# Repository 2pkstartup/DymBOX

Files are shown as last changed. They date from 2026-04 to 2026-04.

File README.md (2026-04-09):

# DymBOX

Regulátor teploty pro udírnu postavený na mikrokontroléru **ATmega8**.

Měří teplotu pomocí DS18B20, zobrazuje ji na 3-místném 7-segmentovém displeji a řídí ventilátor (PWM) a topnou spirálu (ON/OFF s hysterezí). Žádaná teplota a otáčky ventilátoru se nastavují rotačním enkodérem.

## Vlastnosti

- **Měření teploty** – DS18B20 (1-Wire), rozlišení 0.1 °C
- **3-místný 7-segment display** – multiplexovaný v Timer0 ISR (~163 Hz/číslice)
- **Rotační enkodér KY-040** – nastavení žádané teploty a otáček ventilátoru
- **PWM ventilátor** – 11 kroků (0–100 % po 10 %), Timer1 Fast PWM 8-bit na ~977 Hz
- **Topná spirála** – ON/OFF regulace s hysterezí 5 °C
- **Nastavitelný setpoint** – výchozí 32.0 °C, editace po 0.1 °C

## Struktura repozitáře

```
DymBOX/
├── fw/                 # Firmware (C, ATmega8)
│   ├── main.c
│   ├── CMakeLists.txt
│   ├── Makefile
│   ├── cmake/          # AVR-GCC toolchain soubor
│   └── README.md
├── hw/                 # Hardware (KiCad 8)
│   ├── DymBOX_AVR.kicad_sch    # Schéma
│   ├── DymBOX_AVR.kicad_pcb    # PCB layout
│   ├── gerber/                  # Gerber soubory pro výrobu
│   ├── dymbox_gerber.zip        # Zabalené gerbery
│   ├── 2pkstartup.pretty/      # Vlastní footprinty
│   └── DymBOX_AVR-backups/
└── README.md
```

## Hardware

Schéma a PCB jsou navrženy v **KiCadu**. Gerber soubory připravené k výrobě najdete v `hw/gerber/` nebo jako `hw/dymbox_gerber.zip`.

### Hlavní komponenty

| Součástka | Popis |
|---|---|
| ATmega8 | Hlavní MCU (16 MHz) |
| DS18B20 | Digitální teploměr (1-Wire) |
| 3× 7-segment (common anode) | Displej – multiplexovaný |
| KY-040 | Rotační enkodér s tlačítkem |
| Ventilátor | PWM řízený (~977 Hz) |
| Topná spirála | ON/OFF přes PB2 |

### Zapojení pinů

```
PORTB: PB0 = seg A       PB1 = PWM fan    PB2 = heater
PORTC: PC0 = seg E       PC1 = seg D      PC2 = seg DP
       PC3 = seg C       PC4 = seg G      PC5 = DS18B20
PORTD: PD0 = ENC SW      PD1 = DIG3       PD2 = DIG2
       PD3 = ENC CLK     PD4 = ENC DT     PD5 = DIG1
       PD6 = seg B       PD7 = seg F
```

## Firmware

Firmware je napsaný v **C** pro AVR a překládá se pomocí `avr-gcc` + CMake.

### Požadavky

```bash
sudo apt install gcc-avr avr-libc binutils-avr avrdude cmake
```

### Kompilace a nahrání

```bash
cd fw
cmake -B build -DCMAKE_TOOLCHAIN_FILE=cmake/avr-gcc.cmake
cmake --build build              # Kompilace
cmake --build build --target flash   # Nahrání do MCU (USBasp)
cmake --build build --target fuses   # Nastavení fuses
```

### Velikost firmware

```
Program:  ~2186 bytes (26.7 % Flash)
Data:       ~61 bytes  (6.0 % SRAM)
```

## Ovládání

Zařízení má 3 režimy zobrazení:

| Režim | Displej | Ovládání |
|---|---|---|
| **Teplota** (výchozí) | `XX.X` – aktuální teplota | Otočení → ventilátor · Stisk → editace setpointu |
| **Ventilátor** | `FXX` – rychlost v % | Otočení → změna po 10 % · Po 2 s → zpět na teplotu |
| **Editace setpointu** | `XX.X` + DP1 svítí | Otočení → změna po 0.1 °C · Stisk → uložit a zpět |

Topná spirála se indikuje rozsvícením DP3 (poslední tečka).

## Regulace teploty

ON/OFF regulace s hysterezí:

| Podmínka | Akce |
|---|---|
| teplota ≤ setpoint − 5 °C | Spirála **ON** |
| teplota ≥ setpoint | Spirála **OFF** |
| v pásmu hystereze | Beze změny |

## Licence

Tento projekt je volně k použití.

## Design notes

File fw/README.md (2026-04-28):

# dymbox – Regulátor teploty s ATmega8

Regulátor teploty postavený na mikrokontroléru **ATmega8** s 3-místným 7-segmentovým displejem, rotačním enkodérem, teploměrem DS18B20, PWM výstupem pro ventilátor a ON/OFF řízením topné spirály.

## Vlastnosti

- **Měření teploty** – DS18B20 (1-Wire), rozlišení 0.1 °C
- **3-místný 7-segment display** – multiplexovaný v Timer0 ISR (~163 Hz/číslice)
- **Rotační enkodér KY-040** – nastavení žádané teploty a otáček ventilátoru
- **PWM ventilátor** – 21 kroků (0–100 % po 5 %), Timer1 Fast PWM 8-bit na ~488 Hz
- **Topná spirála** – ON/OFF regulace s hysterezí 5 °C, signalizace DP3
- **Nastavitelný setpoint** – výchozí 32.0 °C, editace po 0.1 °C

## Zapojení pinů

### 7-segment display (common anode, active LOW)

| Segment | Pin ATmega8 | Port |
|---|---|---|
| A | PB0 | PORTB |
| B | PD5 | PORTD |
| C | PC3 | PORTC |
| D | PC1 | PORTC |
| E | PC0 | PORTC |
| F | PD7 | PORTD |
| G | PC4 | PORTC |
| DP | PC2 | PORTC |

### Výběr číslic (active LOW)

| Číslice | Pin | Pozice |
|---|-----|---|
| DIG1 | PD6 | Stovky |
| DIG2 | PD2 | Desítky |
| DIG3 | PD1 | Jednotky |

### Rotační enkodér KY-040

| Signál | Pin |
|---|-----|
| CLK (A) | PD3 |
| DT (B)  | PD4 |
| SW | PD0 |
| + | VCC |
| GND | GND |

### DS18B20 teploměr

| Pin DS18B20 | Kam |
|---|-----|
| DQ (data) | PC5 + 4.7 kΩ pull-up na VCC |
| VCC | VCC (3.3–5 V) |
| GND | GND |

### Výstupy

| Funkce | Pin | Typ |
|---|-----|-----|
| Ventilátor (PWM) | PB1 (OC1A) | Fast PWM ~488 Hz |
| Topná spirála | PB2 | SW ON/OFF (active HIGH) |

### Souhrn obsazení pinů

```
PORTB: PB0 = seg A       PB1 = PWM fan    PB2 = heater    PB3–PB5 = volné
PORTC: PC0 = seg E       PC1 = seg D      PC2 = seg DP    PC3 = seg C
       PC4 = seg G       PC5 = DS18B20
PORTD: PD0 = ENC SW      PD1 = DIG3       PD2 = DIG2
       PD3 = ENC CLK     PD4 = ENC DT     PD5 = seg B
       PD6 = DIG1        PD7 = seg F
```

## Ovládání

Aplikace má 3 režimy zobrazení:

### 1. Teplota (výchozí)

Zobrazuje aktuální teplotu ve formátu **XX.X** (tečka za druhým digitem).

- **Otočení enkodéru** → přepne na zobrazení ventilátoru
- **Stisk tlačítka** → přepne do editace setpointu
- **DP3 (poslední tečka)** svítí, pokud topí spirála

### 2. Ventilátor (FXX)

Zobrazuje rychlost ventilátoru ve formátu **FXX** (např. F50 = 50 %). Při 100 % zobrazí **100**.

- **Otočení enkodéru** → mění rychlost po 5 % (0–100 %)
- **Stisk tlačítka** → přepne do editace setpointu
- Po **2 sekundách** bez pohybu se automaticky vrátí na zobrazení teploty

### 3. Editace setpointu

Zobrazuje žádanou teplotu ve formátu **XX.X** s rozsvícenou **DP1** (první tečka) jako indikací editačního režimu.

- **Otočení enkodéru** → mění hodnotu po 0.1 °C (rozsah 0.0–99.9 °C)
- **Stisk tlačítka** → uloží hodnotu a vrátí se na zobrazení teploty

## Regulace teploty

Topná spirála je řízena jednoduchou ON/OFF regulací s hysterezí:

| Podmínka | Akce |
|---|---|
| teplota ≤ setpoint − 5 °C | Spirála **ON** (DP3 svítí) |
| teplota ≥ setpoint | Spirála **OFF** (DP3 nesvítí) |
| v pásmu hystereze | Bez změny |

Výchozí setpoint: **32.0 °C**, hystereze: **5.0 °C** (konstanta `HEATER_HYST`).

## Požadavky

- `avr-gcc`, `avr-libc`, `binutils-avr`
- `avrdude`
- `cmake` (≥ 3.20)
- Programátor USBasp (nebo jiný – viz `PROGRAMMER` v CMakeLists.txt)

### Instalace toolchainu (Debian/Ubuntu)

```bash
sudo apt install gcc-avr avr-libc binutils-avr avrdude
```

## Kompilace a nahrání

```bash
cmake -B build -DCMAKE_TOOLCHAIN_FILE=cmake/avr-gcc.cmake   # Konfigurace
cmake --build build                                          # Kompilace
cmake --build build --target flash                           # Nahrání do MCU
cmake --build build --target fuses                           # Nastavení fuses
```

### Hodnoty fuses (externí krystal 8 MHz)

| Fuse | Hodnota | Popis |
|---|---|---|
| lfuse | `0xFF` | CKSEL=1111 (externí krystal), SUT=11 (65 ms startup) |
| hfuse | `0xD9` | CKOPT=1 (low-power mode), SPIEN povolen |

> **Pozor:** Po nastavení `lfuse=0xFF` ATmega očekává externí krystal. Bez něj chip nenastartuje.

### Velikost firmware

```
Program:  ~2172 bytes (26.5% Full)
Data:       ~71 bytes  (6.9% Full)
```

## Konfigurace

Hlavní konstanty v `main.c`:

| Konstanta | Hodnota | Popis |
|---|---|---|
| `F_CPU` | 8 MHz | Frekvence externího krystalu (CMakeLists.txt) |
| `HEATER_HYST` | 50 (5.0 °C) | Hystereze topné spirály (v 1/10 °C) |
| `HEATER_PERIOD` | 4880 | Perioda ON/OFF cyklu (~10 s) |
| Výchozí setpoint | 320 (32.0 °C) | Žádaná teplota (v 1/10 °C) |
| Výchozí fan | 10 (50 %) | Výchozí rychlost ventilátoru (krok 0–20) |

## Schéma zapojení

```
                    ATmega8
                 ┌───────────┐
    seg A ← PB0 ┤1        28├ PC5 → DS18B20 DQ
  PWM fan ← PB1 ┄2        27┤ PC4 → seg G
   heater ← PB2 ┄3        26┤ PC3 → seg C
           PB3 ┄4        25┤ PC2 → seg DP
           PB4 ┄5        24┤ PC1 → seg D
           PB5 ┄6        23┤ PC0 → seg E
               ┤7        22├ GND
               ┤8        21├ AREF
               ┤9        20├ VCC
               ┤10       19├ PB5 (SCK)
  ENC SW → PD0 ┤11       18├ PB4 (MISO)
    DIG3 ← PD1 ┤12       17├ PB3 (MOSI)
    DIG2 ← PD2 ┤13       16├ PB2
 ENC CLK → PD3 ┤14       15├ PB1
  ENC DT → PD4 ┤15       14├ PD7 → seg F
   seg B ← PD5 ┤16       13├ PD6 → DIG1
                 └───────────┘
```

## Licence

Tento projekt je volně k použití.

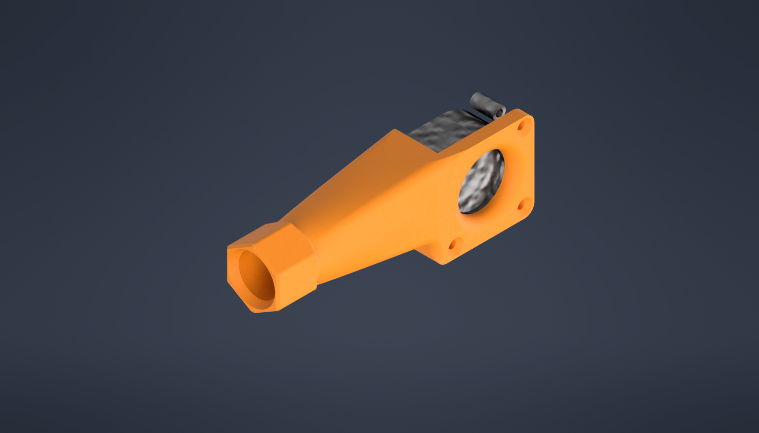
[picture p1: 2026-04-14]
3d/DymBOX-vent02.png

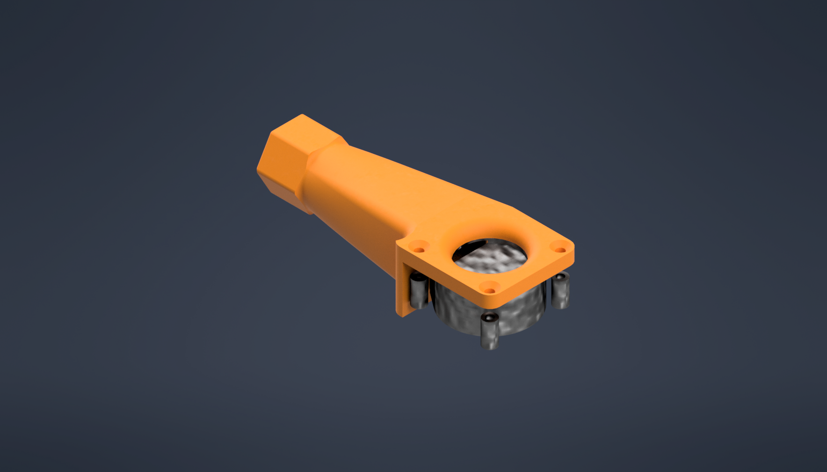
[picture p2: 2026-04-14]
3d/DymBOX-vent01.png

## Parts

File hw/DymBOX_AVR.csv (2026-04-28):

Id | Designator | Footprint | Quantity | Designation | Supplier and ref
1 | C1 | CP_Radial_D16.0mm_P7.50mm | 1 | 3m3F
2 | C2 | C_1206_3216Metric_Pad1.33x1.80mm_HandSolder | 1 | 10uF
3 | C4, C5 | C_0805_2012Metric_Pad1.18x1.45mm_HandSolder | 2 | 22pF
4 | C6 | C_0805_2012Metric_Pad1.18x1.45mm_HandSolder | 1 | C_Small
5 | C8 | C_0805_2012Metric_Pad1.18x1.45mm_HandSolder | 1 | 100nF
6 | C9, C10 | C_0805_2012Metric_Pad1.18x1.45mm_HandSolder | 2 | 22uF
7 | D1, D2 | D_DO-35_SOD27_P7.62mm_Horizontal | 2 | 1N4148
8 | D3 | Diode_Bridge_DIP-4_W5.08mm_P2.54mm | 1 | DB155-YAN
9 | F1 | Fuseholder_Clip-5x20mm_Littelfuse_111_Inline_P20.00x5.00mm_D1.05mm_Horizontal | 1 | 500mA
10 | F2 | Fuseholder_Clip-5x20mm_Littelfuse_111_Inline_P20.00x5.00mm_D1.05mm_Horizontal | 1 | 16A
11 | J1 | faston_6.3 | 1 | L 230V
12 | J2, J3 | faston_6.3 | 2 | N 230V
13 | J4 | faston_6.3 | 1 | Conn_01x01_Pin
14 | J5 | TerminalBlock_Phoenix_PT-1,5-3-3.5-H_1x03_P3.50mm_Horizontal | 1 | TAD05-03-1-L-G
15 | J6 | TerminalBlock_Phoenix_PT-1,5-2-3.5-H_1x02_P3.50mm_Horizontal | 1 | TAD05-02-1-L-G
16 | J7 | PinHeader_2x05_P2.54mm_Vertical | 1 | ZL202-10G
17 | K1 | Relay_SPDT_Schrack-RT1-16A-FormC_RM5mm | 1 | RT314A24
18 | L1 | L_1210_3225Metric_Pad1.42x2.65mm_HandSolder | 1 | 4u7H
19 | Q1, Q2, Q5 | TO-92_HandSolder | 3 | BC327
20 | Q3, Q4 | TO-92_HandSolder | 2 | BS170
21 | R1, R16, R17 | R_Axial_DIN0204_L3.6mm_D1.6mm_P5.08mm_Horizontal | 3 | 10k
22 | R2, R3, R4, R5, R6, R7, R8, R9, R14, R15 | R_Axial_DIN0204_L3.6mm_D1.6mm_P5.08mm_Horizontal | 10 | 330
23 | R10, R11, R12 | R_Axial_DIN0204_L3.6mm_D1.6mm_P5.08mm_Horizontal | 3 | 1k
24 | R13 | R_Axial_DIN0204_L3.6mm_D1.6mm_P5.08mm_Horizontal | 1 | 4k7
25 | SW2 | RotaryEncoder_Alps_EC12E-Switch_Vertical_H20mm_CircularMountingHoles | 1 | RotaryEncoder_Switch
26 | TR1 | Transformer_Breve_TEZ-38x45 | 1 | TEZ6.0-D-1
27 | U1 | DIP-28_W7.62mm | 1 | ATmega8A-P
28 | U2 | FYT-5631BUHR-21 | 1 | FYT-5631BUHR-21
29 | U4 | TSOT-23-6 | 1 | AP63205WU
30 | Y1 | Crystal_HC49-U_Vertical | 1 | 49-8.000MEEJ-B

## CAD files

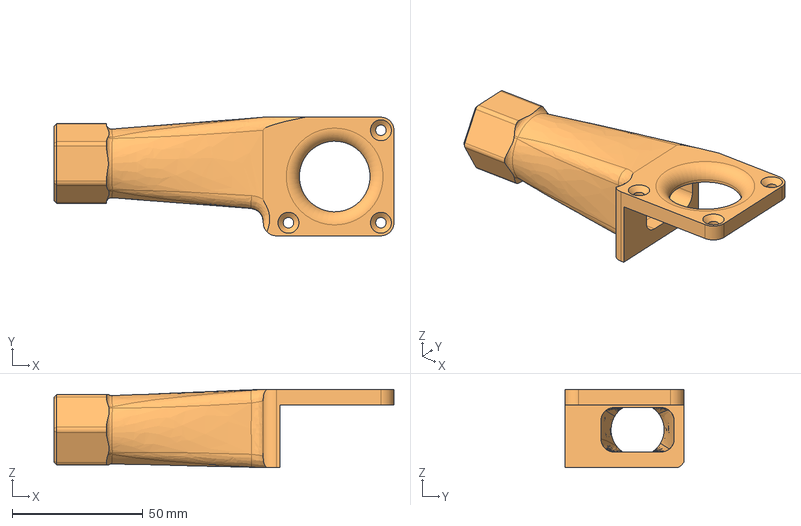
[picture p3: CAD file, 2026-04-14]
3d/DymBOX-ventilator.stp
130.0 x 45.4 x 30.0 mm

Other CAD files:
3d/DymBOX-ventilator.stl

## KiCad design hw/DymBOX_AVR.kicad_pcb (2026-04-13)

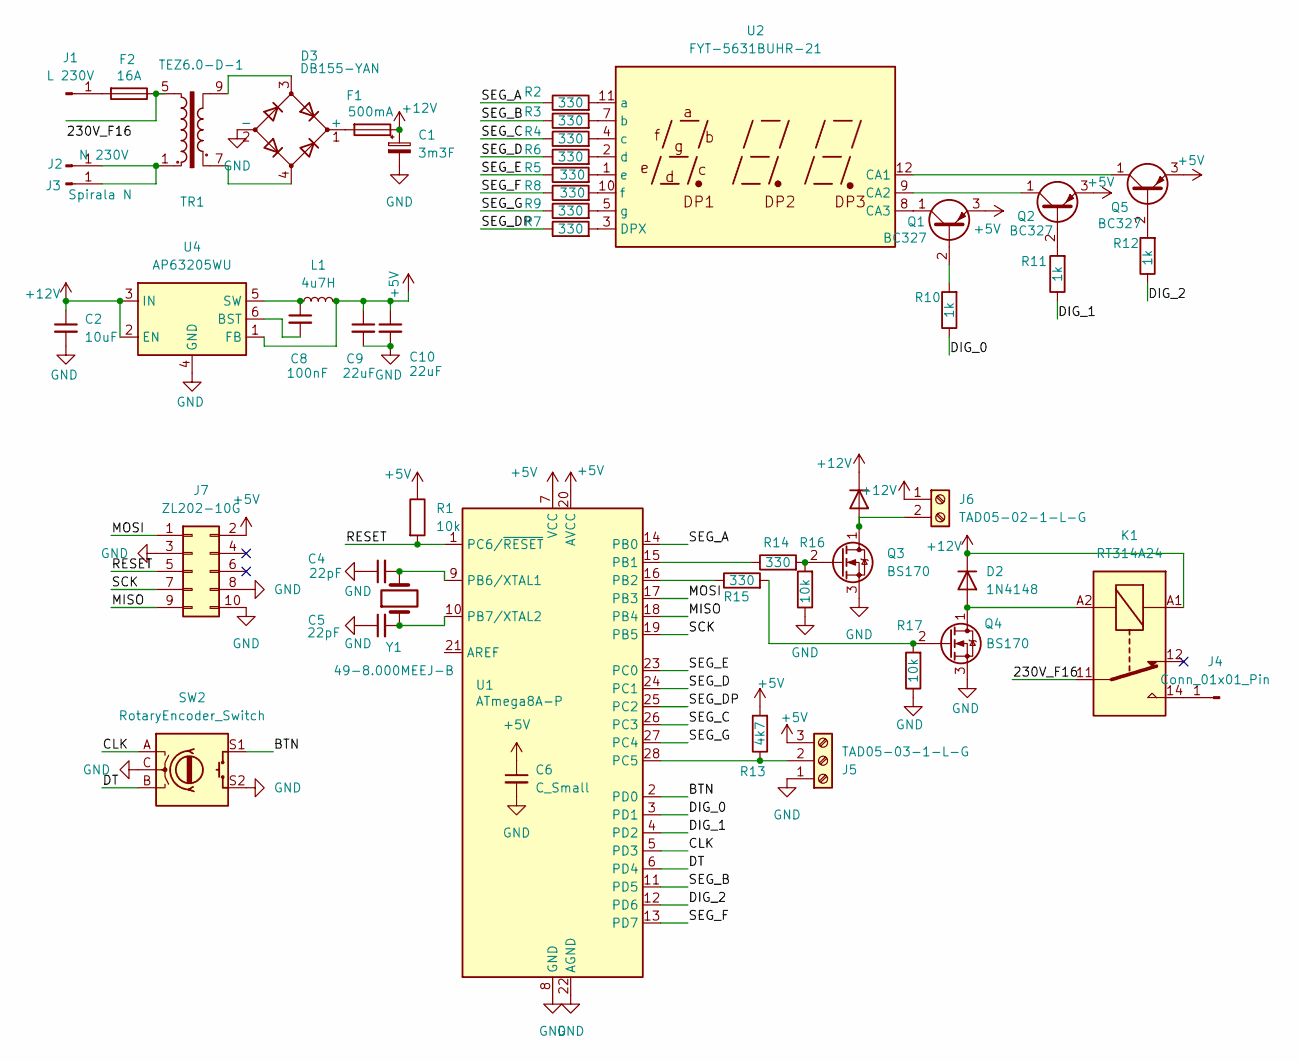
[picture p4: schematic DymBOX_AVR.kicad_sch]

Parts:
C1: 3m3F; CP_Radial_D16.0mm_P7.50mm
C2: 10uF; C_1206_3216Metric_Pad1.33x1.80mm_HandSolder
C4, C5: 22pF; C_0805_2012Metric_Pad1.18x1.45mm_HandSolder
C6: C_Small; C_0805_2012Metric_Pad1.18x1.45mm_HandSolder
C8: 100nF; C_0805_2012Metric_Pad1.18x1.45mm_HandSolder
C9, C10: 22uF; C_0805_2012Metric_Pad1.18x1.45mm_HandSolder
D1, D2: 1N4148; D_DO-35_SOD27_P7.62mm_Horizontal
D3: DB155-YAN; Diode_Bridge_DIP-4_W5.08mm_P2.54mm
F1: 500mA; Fuseholder_Clip-5x20mm_Littelfuse_111_Inline_P20.00x5.00mm_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
F2: 16A; Fuseholder_Clip-5x20mm_Littelfuse_111_Inline_P20.00x5.00mm_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
J1: L 230V; faston_6.3
J2: N 230V; faston_6.3
J3: Spirala N; faston_6.3
J4: Conn_01x01_Pin; faston_6.3
J5: TAD05-03-1-L-G; TerminalBlock_Phoenix_PT-1,5-3-3.5-H_1x03_P3.50mm_Horizontal
J6: TAD05-02-1-L-G; TerminalBlock_Phoenix_PT-1,5-2-3.5-H_1x02_P3.50mm_Horizontal
J7: ZL202-10G; PinHeader_2x05_P2.54mm_Vertical
K1: RT314A24; Relay_SPDT_Schrack-RT1-16A-FormC_RM5mm
L1: 4u7H; L_1210_3225Metric_Pad1.42x2.65mm_HandSolder
Q1, Q2, Q5: BC327; TO-92_HandSolder
Q3, Q4: BS170; TO-92_HandSolder
R1, R16, R17: 10k; R_Axial_DIN0204_L3.6mm_D1.6mm_P5.08mm_Horizontal
R2, R3, R4, R5, R6, R7, R8, R9, R14, R15: 330; R_Axial_DIN0204_L3.6mm_D1.6mm_P5.08mm_Horizontal
R10, R11, R12: 1k; R_Axial_DIN0204_L3.6mm_D1.6mm_P5.08mm_Horizontal
R13: 4k7; R_Axial_DIN0204_L3.6mm_D1.6mm_P5.08mm_Horizontal
SW2: RotaryEncoder_Switch; RotaryEncoder_Alps_EC12E-Switch_Vertical_H20mm_CircularMoun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
TR1: TEZ6.0-D-1; Transformer_Breve_TEZ-38x45
U1: ATmega8A-P; DIP-28_W7.62mm
U2: FYT-5631BUHR-21
U4: AP63205WU; TSOT-23-6
Y1: 49-8.000MEEJ-B; Crystal_HC49-U_Vertical

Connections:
+5V: C6.1, C9.1, C10.1, J5.3, J7.2, L1.2, Q1.3 (E), Q2.3 (E), Q5.3 (E), R1.1, R13.2, U1.7 (VCC), U1.20 (AVCC), U4.1 (FB)
+12V: C1.1, C2.1, D1.1 (K), D2.1 (K), F1.1, J6.1, K1.A1, U4.2 (EN), U4.3 (IN)
/BTN: SW2.S1, U1.2 (PD0)
/CLK: SW2.A, U1.5 (PD3)
/DIG_0: R10.1, U1.3 (PD1)
/DIG_1: R11.1, U1.4 (PD2)
/DIG_2: R12.1, U1.12 (PD6)
/DT: SW2.B, U1.6 (PD4)
/MISO: J7.9, U1.18 (PB4)
/MOSI: J7.1, U1.17 (PB3)
/RESET: J7.5, R1.2, U1.1 (PC6/~RESET)
/SCK: J7.7, U1.19 (PB5)
/SEG_A: R2.1, U1.14 (PB0)
/SEG_B: R3.1, U1.11 (PD5)
/SEG_C: R4.1, U1.26 (PC3)
/SEG_D: R6.1, U1.24 (PC1)
/SEG_DP: R7.1, U1.25 (PC2)
/SEG_E: R5.1, U1.23 (PC0)
/SEG_F: R8.1, U1.13 (PD7)
/SEG_G: R9.1, U1.27 (PC4)
GND: C1.2, C2.2, C4.1, C5.1, C6.2, C9.2, C10.2, D3.2 (-), J5.1, J7.3, J7.8, J7.10, Q3.3 (S), Q4.3 (S), R16.1, R17.1, SW2.C, SW2.S2, U1.8 (GND), U1.22 (AGND), U4.4 (GND)
unnamed: D1.2 (A), J6.2, Q3.1 (D)
unnamed: D2.2 (A), K1.A2, Q4.1 (D)
unnamed: D3.1 (+), F1.2
unnamed: D3.3, TR1.9
unnamed: D3.4, TR1.7
unnamed: F2.2, J1.1 (Pin_1_1)
unnamed: J2.1 (Pin_1_1), J3.1 (Pin_1_1), TR1.1
unnamed: J4.1 (Pin_1_1), K1.14
unnamed: J5.2, R13.1, U1.28 (PC5)
unnamed: Q1.2 (B), R10.2
unnamed: Q1.1 (C), U2.8 (CA3)
unnamed: Q2.2 (B), R11.2
unnamed: Q2.1 (C), U2.9 (CA2)
unnamed: Q3.2 (G), R14.2, R16.2
unnamed: Q4.2 (G), R15.2, R17.2
unnamed: Q5.2 (B), R12.2
unnamed: Q5.1 (C), U2.12 (CA1)
unnamed: R14.1, U1.15 (PB1)
unnamed: R15.1, U1.16 (PB2)
unnamed: C4.2, U1.9 (PB6/XTAL1), Y1.2
unnamed: C5.2, U1.10 (PB7/XTAL2), Y1.1
unnamed: R7.2, U2.3 (DPX)
unnamed: R2.2, U2.11 (a)
unnamed: R3.2, U2.7 (b)
unnamed: R4.2, U2.4 (c)
unnamed: R6.2, U2.2 (d)
unnamed: R5.2, U2.1 (e)
unnamed: R8.2, U2.10 (f)
unnamed: R9.2, U2.5 (g)
unnamed: C8.2, U4.6 (BST)
unnamed: C8.1, L1.1, U4.5 (SW)

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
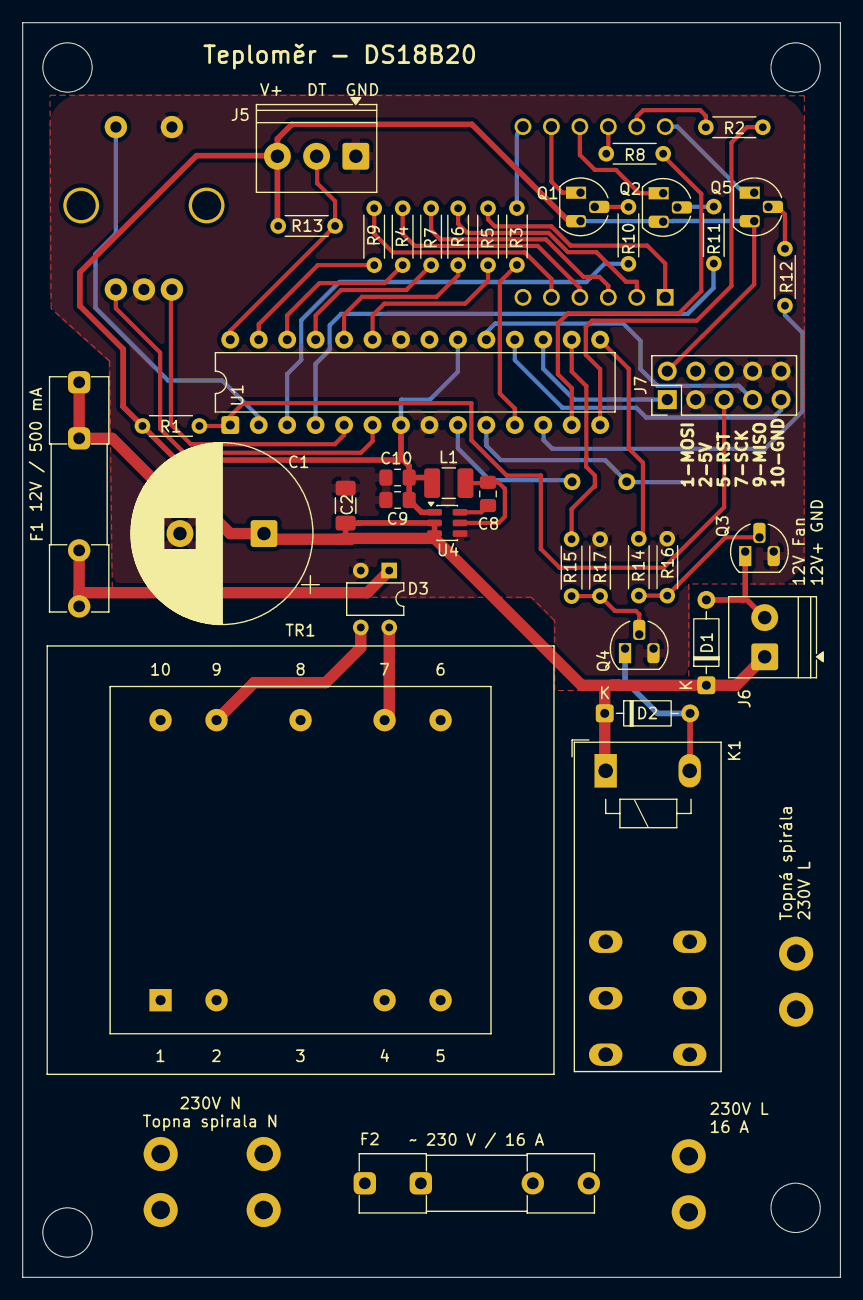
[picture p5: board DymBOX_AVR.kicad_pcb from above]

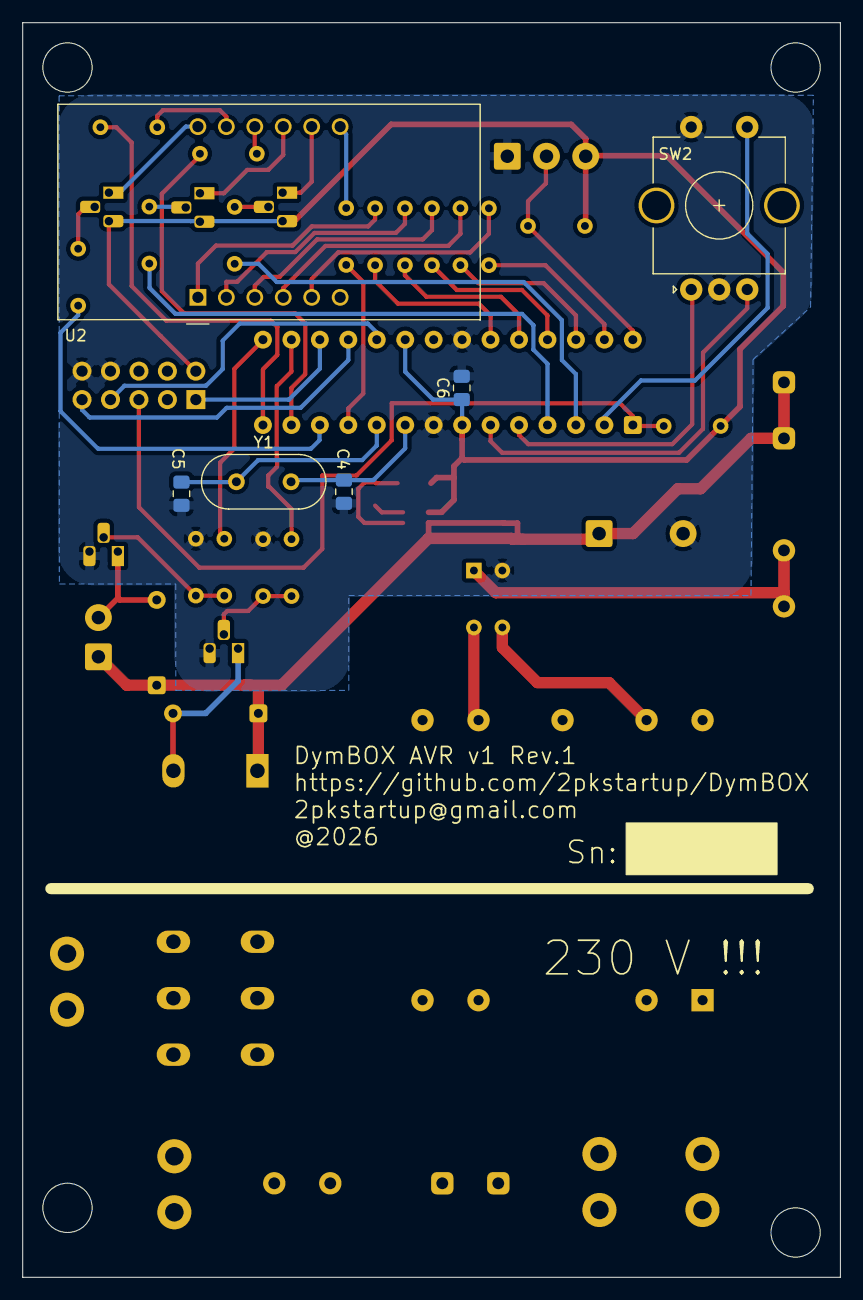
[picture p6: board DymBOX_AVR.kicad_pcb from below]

Board: 2 copper layers, 73.0 x 112.0 mm, 50 parts (6 on the bottom side), 53 nets.

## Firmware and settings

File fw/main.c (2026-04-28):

/*
 * ============================================================================
 * dymbox - Regulátor teploty s ATmega8
 * ============================================================================
 *
 * Popis:
 *   Regulátor teploty pro topnou spirálu s chladícím ventilátorem.
 *   Měření teploty DS18B20, zobrazení na 3-místném 7-segmentovém displeji,
 *   ovládání rotačním enkodérem KY-040. Setpoint uložen v EEPROM.
 *
 * Funkce:
 *   - Měření teploty DS18B20 (1-Wire), rozlišení 0.1 °C
 *   - 3-místný 7-seg display (common anode), multiplexovaný Timer0 ISR
 *   - Rotační enkodér KY-040 (polling v Timer0 ISR, debounce tlačítka)
 *   - PWM ventilátor 0-100% po 10% (Timer1, ~488 Hz, active HIGH)
 *   - Topná spirála ON/OFF s hysterezí 5 °C (active HIGH)
 *   - Setpoint ukládán do EEPROM (s magic byte validací)
 *
 * Režimy zobrazení:
 *   1. Teplota (XX.X) - výchozí, DP3 = spirála topí
 *   2. Ventilátor (FXX/100) - po otočení enkodéru, timeout 2 s
 *   3. Setpoint (XX.X + DP1) - stisk tlačítka, rotací nastavit, stiskem uložit
 *
 * Zapojení pinů ATmega8 (DIP-28):
 *
 *   PORTB:  PB0 = seg A (display)
 *           PB1 = OC1A - PWM ventilátor (active HIGH)
 *           PB2 = topná spirála (active HIGH)
 *           PB3..PB5 = ISP (MOSI, MISO, SCK) / volné
 *
 *   PORTC:  PC0 = seg E        PC3 = seg C
 *           PC1 = seg D        PC4 = seg G
 *           PC2 = seg DP       PC5 = DS18B20 DQ (+ 4.7kΩ pull-up)
 *
 *   PORTD:  PD0 = ENC SW (tlačítko) PD3 = ENC CLK (A)
 *           PD1 = DIG3 (jednotky)   PD4 = ENC DT  (B)
 *           PD2 = DIG2 (desítky)    PD5 = seg B
 *           PD6 = DIG1 (stovky)     PD7 = seg F
 *
 * Schéma:
 *
 *                         ATmega8 (DIP-28)
 *                      ┌────────────────────┐
 *         seg A ← PB0 ─┤1  (PC5) RESET   28├─ PC5 → DS18B20 DQ
 *     PWM fan ← PB1 ─┤2  (PC4)  ADC5   27├─ PC4 → seg G
 *      heater ← PB2 ─┤3  (PC3)  ADC4   26├─ PC3 → seg C
 *    ISP MOSI   PB3 ─┤4  (PC2)  ADC3   25├─ PC2 → seg DP
 *    ISP MISO   PB4 ─┤5  (PC1)  ADC2   24├─ PC1 → seg D
 *     ISP SCK   PB5 ─┤6  (PC0)  ADC1   23├─ PC0 → seg E
 *                     ─┤7  AVCC         22├─ GND
 *                     ─┤8  AREF         21├─ AREF
 *               VCC  ─┤9  VCC          20├─ VCC
 *               GND  ─┤10 GND          19├─ PB5 (SCK)
 *              XTAL1 ─┤11              18├─ PB4 (MISO)
 *              XTAL2 ─┤12              17├─ PB3 (MOSI)
 *      ENC SW → PD0 ─┤13 (RXD)        16├─ PB2 → heater
 *        DIG3 ← PD1 ─┤14 (TXD)        15├─ PB1 → PWM fan
 *        DIG2 ← PD2 ─┤15 (INT0)       14├─ PD7 → seg F
 *     ENC CLK → PD3 ─┤16 (INT1)       13├─ PD6 → DIG1
 *      ENC DT → PD4 ─┤17 (T0)
 *       seg B ← PD5 ─┤18 (T1)
 *                      └────────────────────┘
 *
 *   Display: common anode, segmenty active LOW
 *   Digit select: active LOW (PNP/P-FET)
 *   Výstupy PB1, PB2: active HIGH (pro D4184 MOSFET moduly)
 *   DS18B20: externě 4.7 kΩ pull-up na VCC
 *   KY-040: interní pull-up na PD0, PD3, PD4
 *   F_CPU = 8 MHz
 *
 * Konstanty:
 *   HEATER_HYST    = 5.0 °C (hystereze topné spirály)
 *   HEATER_PERIOD  = 10 s (perioda ON/OFF cyklu)
 *   Výchozí setpoint = 32.0 °C (pokud EEPROM prázdná)
 *   Výchozí fan = 50%
 *
 * ============================================================================
 */

#include <avr/io.h>
#include <avr/interrupt.h>
#include <avr/eeprom.h>
#include <util/delay.h>

/* Masky segmentových pinů na jednotlivých portech */
#define SEG_B_MASK  ((1 << PB0))                                          /* A */
#define SEG_C_MASK  ((1 << PC0)|(1 << PC1)|(1 << PC2)|(1 << PC3)|(1 << PC4)) /* G,C,D,DP,E */
#define SEG_D_MASK  ((1 << PD5)|(1 << PD7))                              /* B,F */

/* Maska digit-select pinů na PORTD */
#define DIG_MASK    ((1 << PD1)|(1 << PD2)|(1 << PD6))

/* Rotační enkodér KY-040 na PORTD */
#define ENC_CLK     PD3
#define ENC_DT      PD4
#define ENC_SW      PD0
#define ENC_MASK    ((1 << ENC_CLK)|(1 << ENC_DT)|(1 << ENC_SW))

/* DS18B20 1-Wire na PC5 */
#define OW_DDR      DDRC
#define OW_PORT     PORTC
#define OW_PIN      PINC
#define OW_BIT      PC5

/* PWM výstupy */
#define PWM1_PIN    PB1   /* OC1A - ventilátor */
#define PWM2_PIN    PB2   /* topná spirála (SW ON/OFF) */

/* Topná spirála: konstanty */
#define HEATER_PERIOD  4880   /* 10 s perioda (488 Hz × 10) */
#define HEATER_HYST    25     /* hystereze 5.0°C (v 1/10 °C) */

/* Pin pro každou pozici: DIG1(stovky)=PD6, DIG2(desítky)=PD2, DIG3(jednotky)=PD1 */
static const uint8_t dig_pin[] = {PD6, PD2, PD1};

/*
 * Lookup tabulky: bity = piny, které mají být LOW (aktivní) pro danou číslici.
 *
 *   Číslice:  0     1     2     3     4     5     6     7     8     9
 *   Seg ON:  ABCDEF BC   ABDEG ABCDG BCFG  ACDFG ACDEFG ABC  ABCDEFG ABCDFG
 */

/*         A=PB0 */
static const uint8_t seg_b[] = {
    0x01, /* 0: A */
    0x00, /* 1:   */
    0x01, /* 2: A */
    0x01, /* 3: A */
    0x00, /* 4:   */
    0x01, /* 5: A */
    0x01, /* 6: A */
    0x01, /* 7: A */
    0x01, /* 8: A */
    0x01, /* 9: A */
};

/*         E=PC0  D=PC1  DP=PC2  C=PC3  G=PC4 */
static const uint8_t seg_c[] = {
    0x0B, /* 0: C,D,E         = (1<<3)|(1<<1)|(1<<0) */
    0x08, /* 1: C             = (1<<3) */
    0x13, /* 2: D,E,G         = (1<<1)|(1<<0)|(1<<4) */
    0x1A, /* 3: C,D,G         = (1<<3)|(1<<1)|(1<<4) */
    0x18, /* 4: C,G           = (1<<3)|(1<<4) */
    0x1A, /* 5: C,D,G         = (1<<3)|(1<<1)|(1<<4) */
    0x1B, /* 6: C,D,E,G       = (1<<3)|(1<<1)|(1<<0)|(1<<4) */
    0x08, /* 7: C             = (1<<3) */
    0x1B, /* 8: C,D,E,G       = (1<<3)|(1<<1)|(1<<0)|(1<<4) */
    0x1A, /* 9: C,D,G         = (1<<3)|(1<<1)|(1<<4) */
};

/*         B=PD5  F=PD7 */
static const uint8_t seg_d[] = {
    0xA0, /* 0: B,F  = (1<<5)|(1<<7) */
    0x20, /* 1: B    = (1<<5) */
    0x20, /* 2: B    = (1<<5) */
    0x20, /* 3: B    = (1<<5) */
    0xA0, /* 4: B,F  = (1<<5)|(1<<7) */
    0x80, /* 5: F    = (1<<7) */
    0x80, /* 6: F    = (1<<7) */
    0x20, /* 7: B    = (1<<5) */
    0xA0, /* 8: B,F  = (1<<5)|(1<<7) */
    0xA0, /* 9: B,F  = (1<<5)|(1<<7) */
};

/* Display buffer: aktivní segmentové bity pro každý port, pro 3 číslice */
/* 0 = vše zhasnuto (žádné segmenty aktivní) */
volatile uint8_t disp_b[3];
volatile uint8_t disp_c[3];
volatile uint8_t disp_d[3];

static volatile uint8_t current_digit = 0;

/* Enkodér: stav a výstupní hodnoty */
static volatile int16_t enc_counter = 0;
static volatile uint8_t enc_button  = 0;   /* 1 = stisknuto (debouncovaně) */
static uint8_t enc_last_clk = 0;
static uint8_t sw_debounce = 0;
static uint8_t sw_last = 0;

/* Timer0 overflow - multiplexing + polling enkodéru (~488 Hz) */
ISR(TIMER0_OVF_vect)
{
    /* --- Display multiplexing --- */

    /* Zhasnout všechny číslice (HIGH = neaktivní) */
    PORTD |= DIG_MASK;

    /* Všechny segmenty OFF (HIGH = pull-up) */
    PORTB |= SEG_B_MASK;
    PORTC |= SEG_C_MASK;
    PORTD |= SEG_D_MASK;

    /* Aktivní segmenty LOW */
    PORTB &= ~disp_b[current_digit];
    PORTC &= ~disp_c[current_digit];
    PORTD &= ~disp_d[current_digit];

    /* Aktivovat aktuální číslici (LOW) */
    PORTD &= ~(1 << dig_pin[current_digit]);

    if (++current_digit >= 3)
        current_digit = 0;

    /* --- Polling enkodéru --- */
    uint8_t pind = PIND;
    uint8_t clk_now = !(pind & (1 << ENC_CLK));

    /* Detekce hrany CLK: falling edge (1->0 v aktivním stavu) */
    if (clk_now && !enc_last_clk) {
        if (pind & (1 << ENC_DT))
            enc_counter--;
        else
            enc_counter++;
    }
    enc_last_clk = clk_now;

    /* Debounce tlačítka (~8 ms = 4 vzorky při 488 Hz) */
    uint8_t sw_now = !(pind & (1 << ENC_SW));
    if (sw_now == sw_last) {
        if (sw_debounce < 4)
            sw_debounce++;
        if (sw_debounce >= 4)
            enc_button = sw_now;
    } else {
        sw_debounce = 0;
    }
    sw_last = sw_now;
}

static void display_init(void)
{
    /* PORTB: PB0 výstup (seg A), PB1/PB2 výstup (active HIGH, start LOW), ostatní pull-up */
    DDRB  = SEG_B_MASK | (1 << PWM1_PIN) | (1 << PWM2_PIN);
    PORTB = 0xFF & ~(1 << PWM1_PIN) & ~(1 << PWM2_PIN);  /* PB1,PB2 start LOW */

    /* PORTC: PC0-PC4 výstup (segmenty), PC5 vstup s pull-up (1-Wire idle) */
    DDRC  = SEG_C_MASK;
    PORTC = 0x3F;

    /* PORTD: PD1,PD2,PD6 výstup (digit), PD5,PD7 výstup (seg B,F), PD0,PD3,PD4 vstup s pull-up */
    DDRD  = DIG_MASK | SEG_D_MASK;  /* PD0,PD3,PD4 zůstávají vstup */
    PORTD = 0xFF;                   /* pull-up na všech (i enkodér) */

    /* Timer0: prescaler 64, overflow interrupt */
    /* 8 MHz / 64 / 256 = ~488 Hz */
    TCCR0 = (1 << CS01) | (1 << CS00);
    TIMSK |= (1 << TOIE0);
}

/* Zobrazit 3-místné číslo 0-999 */
void display_number(uint16_t num)
{
    if (num > 999)
        num = 999;

    uint8_t d2 = num % 10; num /= 10;
    uint8_t d1 = num % 10; num /= 10;
    uint8_t d0 = num % 10;

    disp_b[0] = seg_b[d0]; disp_c[0] = seg_c[d0]; disp_d[0] = seg_d[d0];
    disp_b[1] = seg_b[d1]; disp_c[1] = seg_c[d1]; disp_d[1] = seg_d[d1];
    disp_b[2] = seg_b[d2]; disp_c[2] = seg_c[d2]; disp_d[2] = seg_d[d2];
}

/* Nastavit jednu číslici (pos 0-2), volitelně s desetinnou tečkou */
void display_digit(uint8_t pos, uint8_t value, uint8_t dp)
{
    if (pos > 2 || value > 9)
        return;

    disp_b[pos] = seg_b[value];
    disp_c[pos] = seg_c[value];
    disp_d[pos] = seg_d[value];

    if (dp)
        disp_c[pos] |= (1 << PC2);  /* DP ON (active LOW = přidat do active masky) */
}

/* Zhasnout celý display */
void display_off(void)
{
    for (uint8_t i = 0; i < 3; i++) {
        disp_b[i] = 0;
        disp_c[i] = 0;
        disp_d[i] = 0;
    }
}

/* Přečíst aktuální hodnotu enkodéru (atomicky) */
int16_t encoder_get(void)
{
    cli();
    int16_t val = enc_counter;
    sei();
    return val;
}

/* Nastavit hodnotu enkodéru */
void encoder_set(int16_t val)
{
    cli();
    enc_counter = val;
    sei();
}

/* Přečíst stav tlačítka (1 = stisknuto) */
uint8_t encoder_button(void)
{
    return enc_button;
}

/* ====== 1-Wire protokol (DS18B20) ====== */

static uint8_t ow_reset(void)
{
    uint8_t presence;
    cli();
    OW_DDR |= (1 << OW_BIT);    /* LOW */
    OW_PORT &= ~(1 << OW_BIT);
    _delay_us(480);
    OW_DDR &= ~(1 << OW_BIT);   /* uvolnit (pull-up externí) */
    OW_PORT &= ~(1 << OW_BIT);  /* bez interního pull-up */
    _delay_us(70);
    presence = !(OW_PIN & (1 << OW_BIT));
    sei();
    _delay_us(410);
    return presence;
}

static void ow_write_bit(uint8_t bit)
{
    cli();
    OW_DDR |= (1 << OW_BIT);
    OW_PORT &= ~(1 << OW_BIT);
    if (bit) {
        _delay_us(6);
        OW_DDR &= ~(1 << OW_BIT);
        sei();
        _delay_us(64);
    } else {
        _delay_us(60);
        OW_DDR &= ~(1 << OW_BIT);
        sei();
        _delay_us(10);
    }
}

static uint8_t ow_read_bit(void)
{
    uint8_t bit;
    cli();
    OW_DDR |= (1 << OW_BIT);
    OW_PORT &= ~(1 << OW_BIT);
    _delay_us(6);
    OW_DDR &= ~(1 << OW_BIT);
    _delay_us(9);
    bit = !!(OW_PIN & (1 << OW_BIT));
    sei();
    _delay_us(55);
    return bit;
}

static void ow_write_byte(uint8_t data)
{
    for (uint8_t i = 0; i < 8; i++) {
        ow_write_bit(data & 0x01);
        data >>= 1;
    }
}

static uint8_t ow_read_byte(void)
{
    uint8_t data = 0;
    for (uint8_t i = 0; i < 8; i++)
        data |= (ow_read_bit() << i);
    return data;
}

/* Spustit konverzi teploty (trvá až 750 ms) */
void ds18b20_start(void)
{
    ow_reset();
    ow_write_byte(0xCC);  /* Skip ROM */
    ow_write_byte(0x44);  /* Convert T */
}

/* Přečíst teplotu v 1/10 °C (např. 235 = 23.5°C). Vrátí -999 při chybě. */
int16_t ds18b20_read_temp(void)
{
    if (!ow_reset())
        return -999;

    ow_write_byte(0xCC);  /* Skip ROM */
    ow_write_byte(0xBE);  /* Read Scratchpad */

    uint8_t lsb = ow_read_byte();
    uint8_t msb = ow_read_byte();

    int16_t raw = (int16_t)((msb << 8) | lsb);
    /* raw je v 1/16 °C, převod na 1/10 °C: raw * 10 / 16 */
    return (raw * 10 + 8) / 16;
}

/* Zobrazit teplotu na displeji: XX.X (s tečkou za druhým digitem) */
/* Pokud heater_active = 1, rozsvítí DP3 */
static uint8_t heater_active = 0;

static void display_temp(int16_t temp_x10)
{
    if (temp_x10 < 0 || temp_x10 > 999)
        temp_x10 = 0;

    uint8_t d2 = temp_x10 % 10; temp_x10 /= 10;
    uint8_t d1 = temp_x10 % 10; temp_x10 /= 10;
    uint8_t d0 = temp_x10 % 10;

    disp_b[0] = seg_b[d0]; disp_c[0] = seg_c[d0]; disp_d[0] = seg_d[d0];
    /* DIG2 s desetinnou tečkou */
    disp_b[1] = seg_b[d1]; disp_c[1] = seg_c[d1] | (1 << PC2); disp_d[1] = seg_d[d1];
    /* DIG3: DP3 svítí když topí spirála */
    disp_b[2] = seg_b[d2]; disp_c[2] = seg_c[d2]; disp_d[2] = seg_d[d2];
    if (heater_active)
        disp_c[2] |= (1 << PC2);
}

/* Zobrazit žádanou hodnotu: XX.X s DP1 (první tečka) jako indikace editačního režimu */
static void display_setpoint(int16_t sp_x10)
{
    if (sp_x10 < 0 || sp_x10 > 999)
        sp_x10 = 0;

    uint8_t d2 = sp_x10 % 10; sp_x10 /= 10;
    uint8_t d1 = sp_x10 % 10; sp_x10 /= 10;
    uint8_t d0 = sp_x10 % 10;

    /* DIG1 s DP (indikace edit módu) */
    disp_b[0] = seg_b[d0]; disp_c[0] = seg_c[d0] | (1 << PC2); disp_d[0] = seg_d[d0];
    /* DIG2 s desetinnou tečkou */
    disp_b[1] = seg_b[d1]; disp_c[1] = seg_c[d1] | (1 << PC2); disp_d[1] = seg_d[d1];
    disp_b[2] = seg_b[d2]; disp_c[2] = seg_c[d2]; disp_d[2] = seg_d[d2];
}

/* Čekání na uvolnění tlačítka enkodéru */
static void wait_button_release(void)
{
    while (encoder_button())
        ;
    _delay_ms(50);  /* krátký debounce po uvolnění */
}

/* ====== PWM ventilátor (Timer1, OC1A = PB1) ====== */

/* Invertovaná tabulka: 0%=0(LOW), 10%=25, ... 100%=255(HIGH) */
static const uint8_t pwm_table[] = {
    0, 13, 26, 38, 51, 64, 77, 89, 102, 115, 128,
    140, 153, 166, 179, 191, 204, 217, 230, 242, 255
};

static void pwm_init(void)
{
    /* Timer1: Fast PWM 8-bit, non-inverting na OC1A (PB1) */
    /* HIGH když counter < OCR1A, LOW když counter >= OCR1A */
    /* 8 MHz / 64 / 256 = ~488 Hz (D4184 nezvládá vysoké frekvence) */
    TCCR1A = (1 << COM1A1) | (1 << WGM10);
    TCCR1B = (1 << WGM12) | (1 << CS11) | (1 << CS10);
    OCR1A  = pwm_table[10];  /* 50% výchozí */
}

static void pwm_set(uint8_t step)
{
    if (step > 20) step = 20;
    OCR1A = pwm_table[step];
}

/* Zobrazit fan speed: "FXX" (0-95%) nebo "100" */
#define CHAR_F_B  0x01        /* A=PB0 */
#define CHAR_F_C  0x11        /* E=PC0, G=PC4 */
#define CHAR_F_D  0x80        /* F=PD7 */

static void display_fan(uint8_t fan_pct)
{
    if (fan_pct >= 100) {
        /* "100" */
        disp_b[0] = seg_b[1]; disp_c[0] = seg_c[1]; disp_d[0] = seg_d[1];
        disp_b[1] = seg_b[0]; disp_c[1] = seg_c[0]; disp_d[1] = seg_d[0];
        disp_b[2] = seg_b[0]; disp_c[2] = seg_c[0]; disp_d[2] = seg_d[0];
    } else {
        /* "FXX" */
        disp_b[0] = CHAR_F_B; disp_c[0] = CHAR_F_C; disp_d[0] = CHAR_F_D;
        uint8_t tens  = fan_pct / 10;
        uint8_t units = fan_pct % 10;
        disp_b[1] = seg_b[tens];  disp_c[1] = seg_c[tens];  disp_d[1] = seg_d[tens];
        disp_b[2] = seg_b[units]; disp_c[2] = seg_c[units]; disp_d[2] = seg_d[units];
    }
}

/* ====== Topná spirála (ON/OFF s hysterezí, PB2) ====== */

static void heater_set(uint8_t on)
{
    heater_active = on;
    if (on)
        PORTB |= (1 << PWM2_PIN);   /* HIGH = aktivní */
    else
        PORTB &= ~(1 << PWM2_PIN);  /* LOW = neaktivní */
}

/* Vyhodnotit stav spirály na základě teploty a setpointu */
static void heater_update(int16_t temp_x10, int16_t setpoint_x10)
{
    if (temp_x10 <= setpoint_x10 - HEATER_HYST)
        heater_set(1);
    else if (temp_x10 >= setpoint_x10)
        heater_set(0);
    /* v pásmu hystereze: ponechat současný stav */
}

/* ====== EEPROM: uložení setpointu ====== */

#define EEPROM_MAGIC     0xDB   /* kontrolní byte pro validaci */
#define EEPROM_ADDR_MAGIC  ((uint8_t *)0)
#define EEPROM_ADDR_SP     ((int16_t *)1)

static int16_t eeprom_load_setpoint(int16_t default_val)
{
    if (eeprom_read_byte(EEPROM_ADDR_MAGIC) != EEPROM_MAGIC)
        return default_val;

    int16_t val = eeprom_read_word((uint16_t *)EEPROM_ADDR_SP);
    if (val < 0 || val > 999)
        return default_val;

    return val;
}

static void eeprom_save_setpoint(int16_t val)
{
    eeprom_update_byte(EEPROM_ADDR_MAGIC, EEPROM_MAGIC);
    eeprom_update_word((uint16_t *)EEPROM_ADDR_SP, (uint16_t)val);
}

/* ====== Hlavní program ====== */

#define MODE_TEMP      0
#define MODE_FAN       1
#define MODE_SETPOINT  2

int main(void)
{
    display_init();
    pwm_init();
    sei();

    int16_t setpoint = eeprom_load_setpoint(320);  /* z EEPROM nebo 32.0°C */
    int8_t  fan_step = 10;    /* 50% */
    uint8_t mode = MODE_TEMP;
    uint8_t fan_timeout = 0;  /* odpočet 2 s (40 × 50 ms) */
    int16_t last_enc;

    ds18b20_start();
    _delay_ms(750);
    last_enc = encoder_get();

    while (1) {
        /* Přečíst delta enkodéru */
        int16_t enc_now = encoder_get();
        int16_t delta   = enc_now - last_enc;
        last_enc = enc_now;

        switch (mode) {

        /* --- Teplota (normální režim) --- */
        case MODE_TEMP:
        {
            int16_t temp = ds18b20_read_temp();
            ds18b20_start();
            heater_update(temp, setpoint);
            display_temp(temp);

            /* Rotace enkodéru → přepni na fan */
            if (delta) {
                fan_step += delta;
                if (fan_step < 0)  fan_step = 0;
                if (fan_step > 20) fan_step = 20;
                pwm_set(fan_step);
                display_fan(fan_step * 5);
                fan_timeout = 40;  /* 2 s */
                mode = MODE_FAN;
                break;
            }

            /* Stisk tlačítka → editace setpointu */
            if (encoder_button()) {
                wait_button_release();
                mode = MODE_SETPOINT;
                display_setpoint(setpoint);
            }

            _delay_ms(250);
            break;
        }

        /* --- Zobrazení fan rychlosti --- */
        case MODE_FAN:
        {
            if (delta) {
                fan_step += delta;
                if (fan_step < 0)  fan_step = 0;
                if (fan_step > 20) fan_step = 20;
                pwm_set(fan_step);
                display_fan(fan_step * 5);
                fan_timeout = 40;  /* reset timeoutu */
            }

            /* Tlačítko → editace setpointu */
            if (encoder_button()) {
                wait_button_release();
                mode = MODE_SETPOINT;
                display_setpoint(setpoint);
                break;
            }

            /* Timeout → zpět na teplotu */
            if (--fan_timeout == 0) {
                mode = MODE_TEMP;
                ds18b20_start();
                _delay_ms(750);
            }

            _delay_ms(50);
            break;
        }

        /* --- Editace žádané hodnoty --- */
        case MODE_SETPOINT:
        {
            setpoint += delta;
            if (setpoint < 0)   setpoint = 0;
            if (setpoint > 999) setpoint = 999;

            display_setpoint(setpoint);

            /* Stisk tlačítka → ulož a vrať se */
            if (encoder_button()) {
                eeprom_save_setpoint(setpoint);
                wait_button_release();
                mode = MODE_TEMP;
                ds18b20_start();
                _delay_ms(750);
            }

            _delay_ms(50);
            break;
        }
        }
    }

    return 0;
}

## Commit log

2026-04-10 uprava a více
    [DymBOX_AVR.kicad_pcb, DymBOX_AVR.kicad_sch]
2026-04-10 úpravy
    [DymBOX_AVR.kicad_pcb]
2026-04-13 pojistka16A a další
    [DymBOX_AVR-B_Cu.gbr, DymBOX_AVR-B_Mask.gbr, DymBOX_AVR-B_Silkscreen.gbr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]
2026-04-13 final v01
    [DymBOX_AVR-B_Cu.gbr, DymBOX_AVR-B_Mask.gbr, DymBOX_AVR-B_Silkscreen.gbr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]
2026-04-13 final v02
    [DymBOX_AVR-B_Cu.gbr, DymBOX_AVR-B_Mask.gbr, DymBOX_AVR-B_Silkscreen.gbr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]
2026-04-14 3d modely
    [DymBOX-ventilator.stl, DymBOX-ventilator.stp]
2026-04-28 final assembly finish
    [DymBOX_AVR.csv]
